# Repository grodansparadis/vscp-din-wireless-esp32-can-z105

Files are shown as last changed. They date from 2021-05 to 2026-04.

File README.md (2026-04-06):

# vscp-din-wireless-esp32-z105
ESP32 based CAN4VSCP FD controller in a single module DIN package with BT and wifi interface.

**Note!** This is still a prototype. ....

The bottom board is here: https://github.com/grodansparadis/vscp-din-m1-base-board-z105

## PCB's
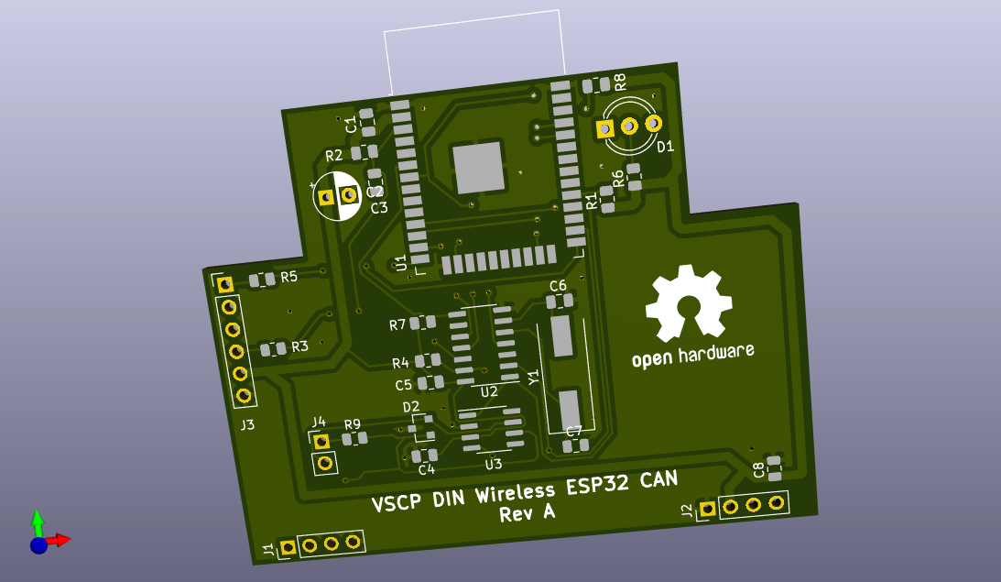
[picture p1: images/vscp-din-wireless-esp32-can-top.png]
Control Interface Top


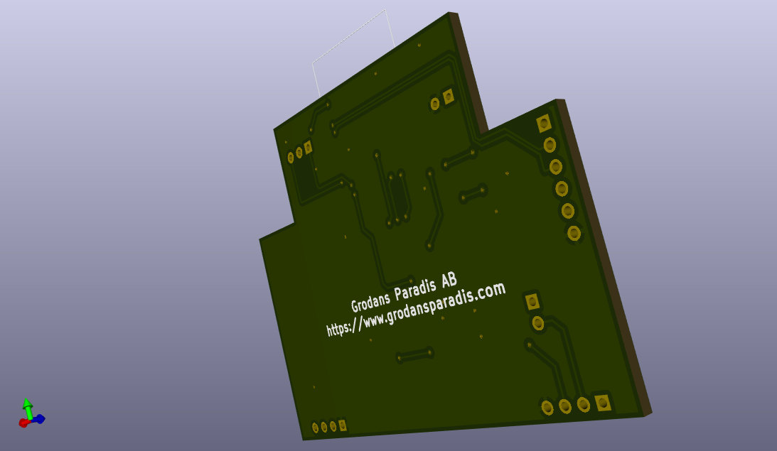
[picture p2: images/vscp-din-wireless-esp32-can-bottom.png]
Control Interface Bottom
 

---

Part of the [VSCP Project](https://www.vscp.org).

Copyright 2021-2026 © Åke Hedman, (Grodans Paradis AB)[https://www.grodansparadis.com]

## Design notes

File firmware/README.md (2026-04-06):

# No firmware here

Firmware is available here: https://github.com/grodansparadis/vscp-din-wireless-esp32-can-z102

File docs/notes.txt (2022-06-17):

CAN Driver
----------
https://github.com/ThomasBarth/ESP32-CAN-Driver

CAN interface using ESP32
-------------------------
https://github.com/nopnop2002/esp-idf-CANBus-Monitor

Open standard for connecting devices to Wi-Fi using Bluetooth LE or Serial
--------------------------------------------------------------------------
https://www.improv-wifi.com/

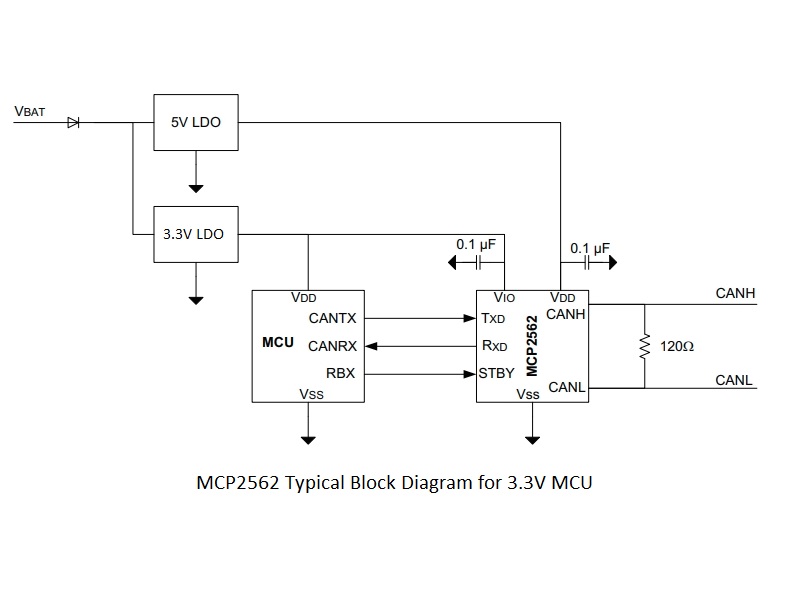
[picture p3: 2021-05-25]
docs/MCP2562-Block-Diagram.jpg

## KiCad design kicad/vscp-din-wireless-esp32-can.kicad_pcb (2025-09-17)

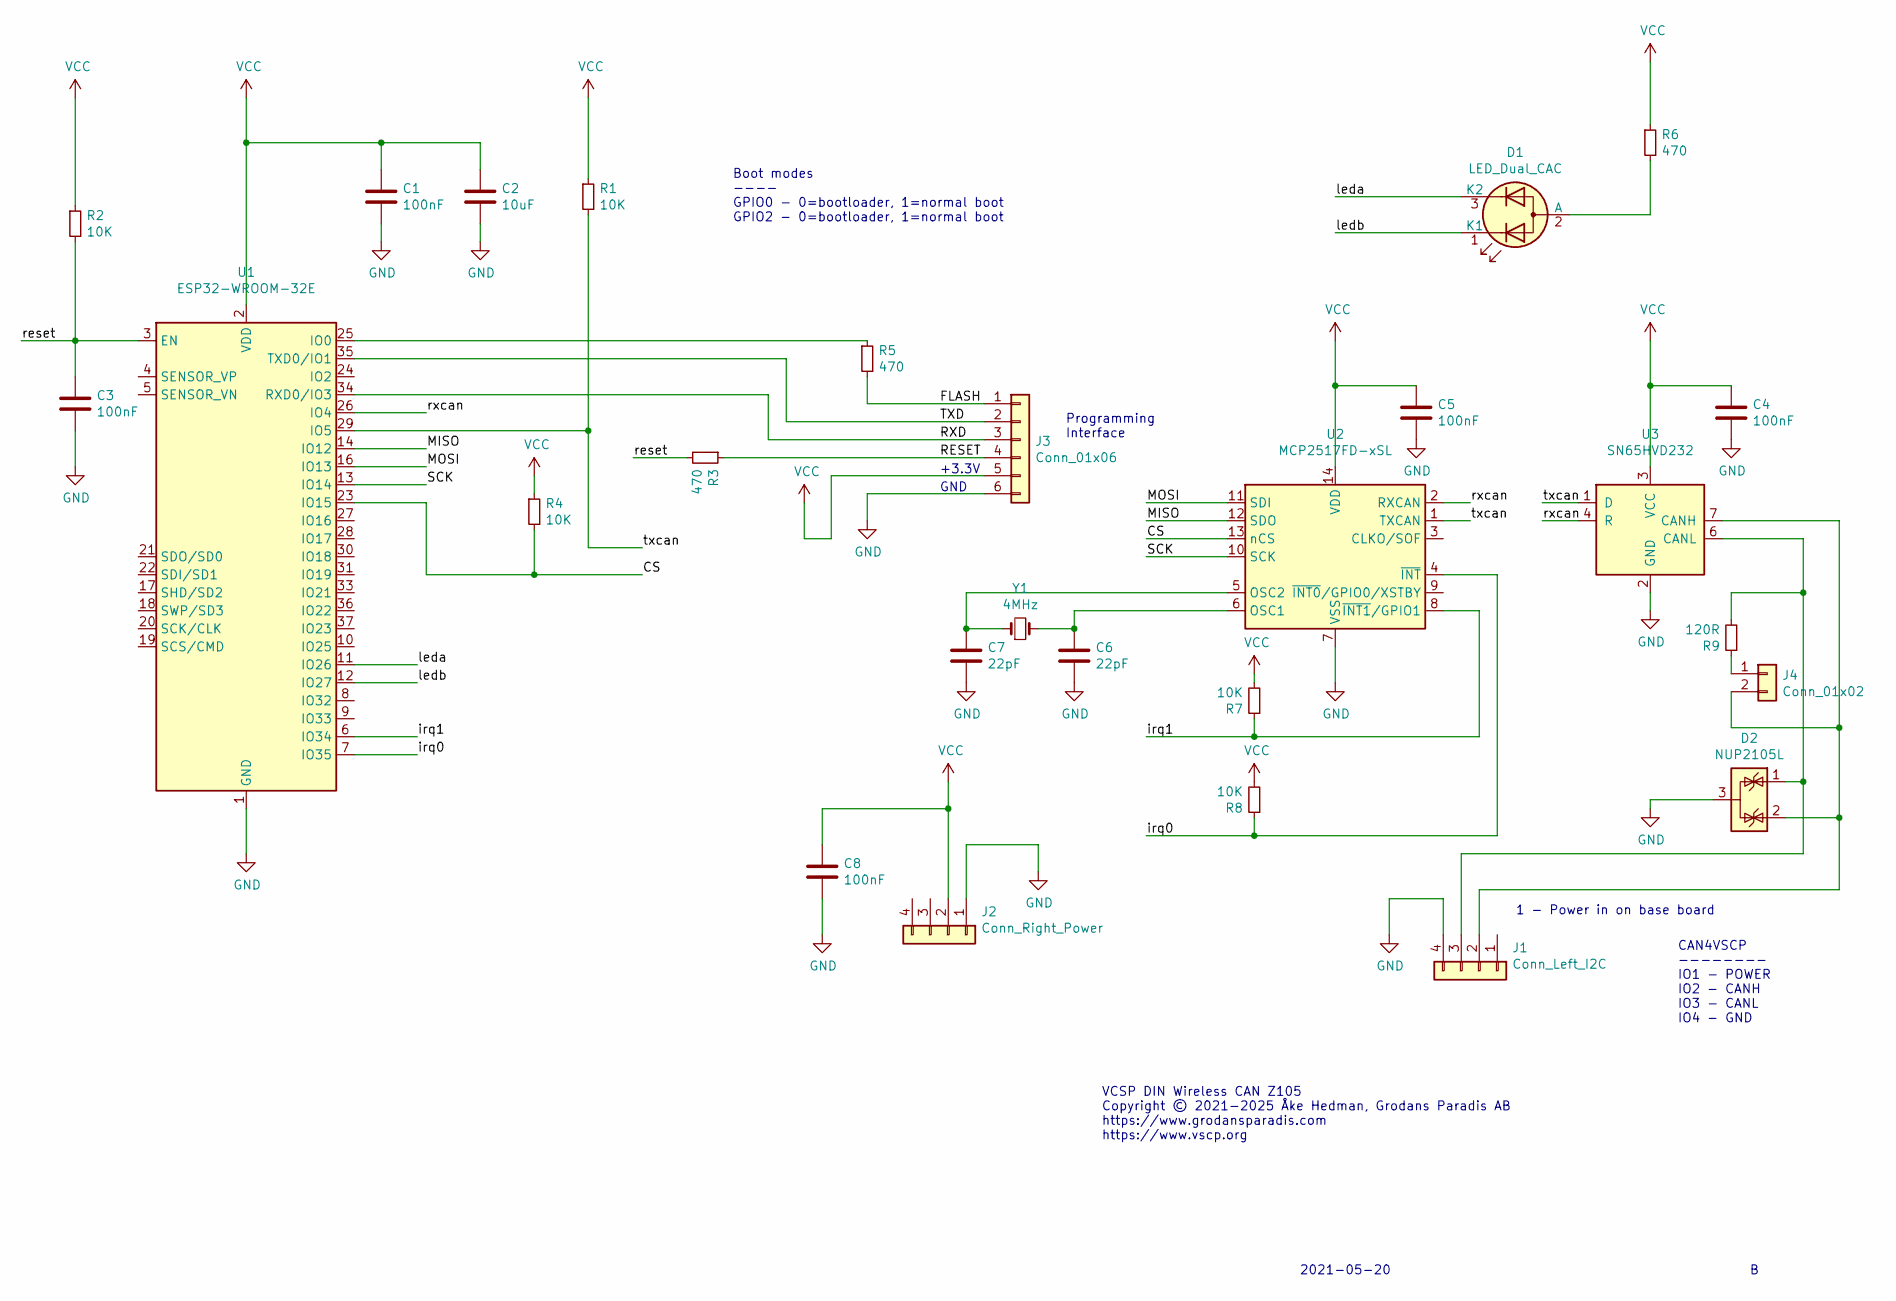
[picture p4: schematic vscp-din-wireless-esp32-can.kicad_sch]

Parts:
C1, C3, C4, C5, C8: 100nF; C_0805_2012Metric
C2: 10uF; CP_Radial_D5.0mm_P2.50mm
C6, C7: 22pF; C_0805_2012Metric
D1: LED_Dual_CAC; LED_D5.0mm-3
D2: NUP2105L; SOT-23
J1: Conn_Left_I2C; PinHeader_1x04_P2.54mm_Vertical
J2: Conn_Right_Power; PinHeader_1x04_P2.54mm_Vertical
J3: Conn_01x06; PinHeader_1x06_P2.54mm_Vertical
J4: Conn_01x02; PinHeader_1x02_P2.54mm_Vertical
R1, R2, R4, R7, R8: 10K; R_0805_2012Metric
R3, R5, R6: 470; R_0805_2012Metric
R9: 120R; R_0805_2012Metric
U1: ESP32-WROOM-32E; ESP32-WROOM-32
U2: MCP2517FD-xSL; SOIC-14_3.9x8.7mm_P1.27mm
U3: SN65HVD232; SOIC-8_3.9x4.9mm_P1.27mm
Y1: 4MHz; Crystal_SMD_HC49-SD

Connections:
/CS: R4.2, U1.23 (IO15), U2.13 (nCS)
/FLASH: J3.1, R5.2
/MISO: U1.14 (IO12), U2.12 (SDO)
/MOSI: U1.16 (IO13), U2.11 (SDI)
/RESET: J3.4, R3.1
/RXD: J3.3, U1.34 (RXD0/IO3)
/SCK: U1.13 (IO14), U2.10 (SCK)
/TXD: J3.2, U1.35 (TXD0/IO1)
/irq0: R8.1, U1.7 (IO35), U2.4 (~INT)
/irq1: R7.1, U1.6 (IO34), U2.8 (~INT1/GPIO1)
/leda: D1.3 (K2), U1.11 (IO26)
/ledb: D1.1 (K1), U1.12 (IO27)
/reset: C3.1, R2.2, R3.2, U1.3 (EN)
/rxcan: U1.26 (IO4), U2.2 (RXCAN), U3.4 (R)
/txcan: R1.2, U1.29 (IO5), U2.1 (TXCAN), U3.1 (D)
GND: C1.2, C2.2, C3.2, C4.2, C5.2, C6.2, C7.2, C8.2, D2.3 (A), J1.4, J2.1, J3.6, U1.1 (GND), U1.15 (GND), U1.38 (GND), U1.39 (GND), U2.7 (VSS), U3.2 (GND)
unnamed: D1.2 (A), R6.2
unnamed: D2.2 (K), J1.2, J4.2, U3.7 (CANH)
unnamed: D2.1 (K), J1.3, R9.2, U3.6 (CANL)
unnamed: J4.1, R9.1
unnamed: R5.1, U1.25 (IO0)
unnamed: C6.1, U2.6 (OSC1), Y1.2
unnamed: C7.1, U2.5 (OSC2), Y1.1
VCC: C1.1, C2.1, C4.1, C5.1, C8.1, J2.2, J3.5, R1.1, R2.1, R4.1, R6.1, R7.2, R8.2, U1.2 (VDD), U2.14 (VDD), U3.3 (VCC)

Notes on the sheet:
+3.3V
2021-05-20
VCSP DIN Wireless CAN Z105 Copyright © 2021-2025 Åke Hedman, Grodans Paradis AB https://www.grodansparadis.com https://www.vscp.org
GND
CAN4VSCP -------- IO1 - POWER IO2 - CANH IO3 - CANL IO4 - GND
Boot modes ---- GPIO0 - 0=bootloader, 1=normal boot GPIO2 - 0=bootloader, 1=normal boot
Programming Interface
1 - Power in on base board

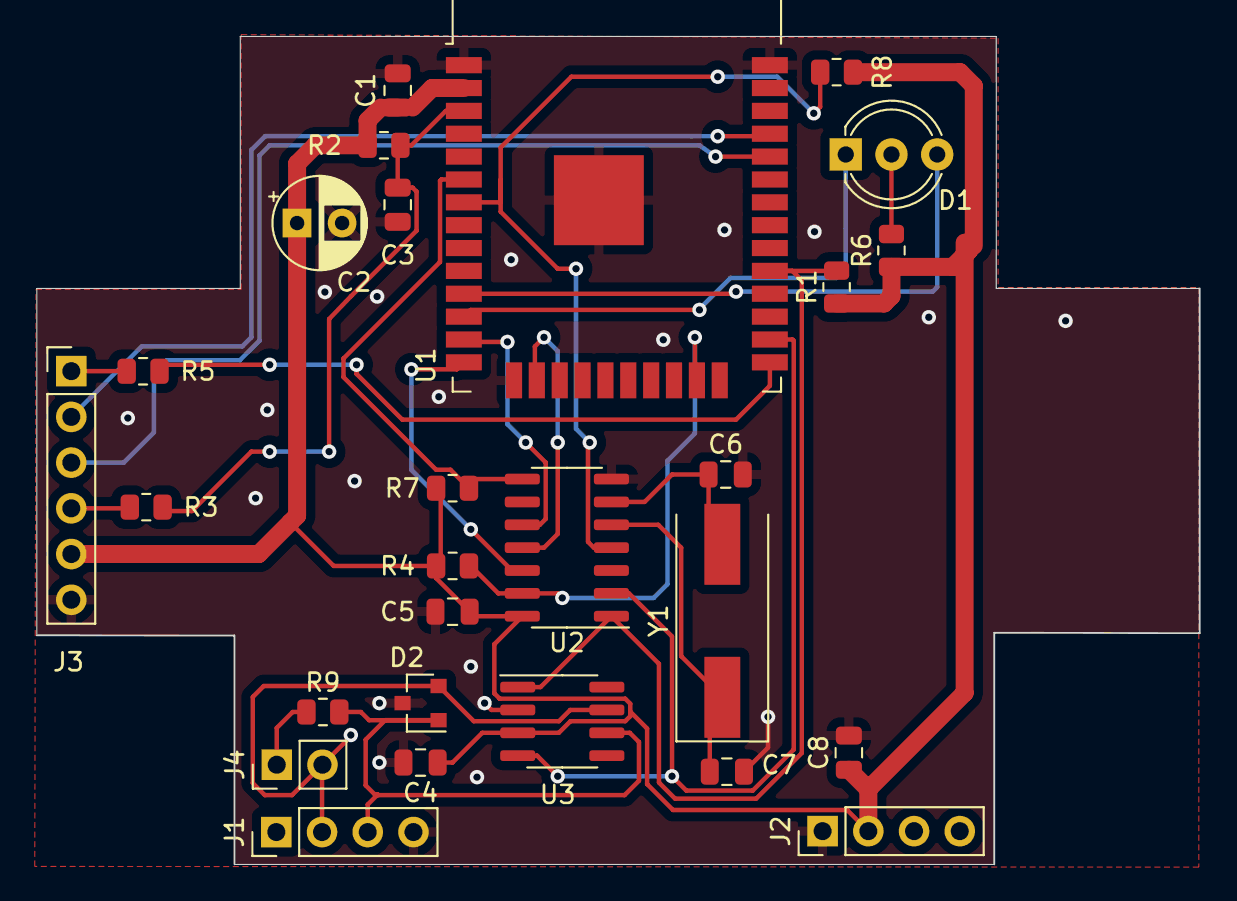
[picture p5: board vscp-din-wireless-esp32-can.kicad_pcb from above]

Board: 2 copper layers, 64.6 x 46.0 mm, 27 parts (0 on the bottom side), 24 nets.

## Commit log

2021-05-24 Init import
    [vscp-din-wireless-esp32-can.kicad_pcb, vscp-din-wireless-esp32-can.sch]
2021-05-25 First version gerbers
    [vscp-din-wireless-esp32-can.kicad_pcb, vscp-din-wireless-esp32-can.sch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]
2021-05-25 Added gerbers
    [vscp-din-wireless-esp32-can-B_Cu.gbr, vscp-din-wireless-esp32-can-B_Mask.gbr, vscp-din-wireless-esp32-can-B_Paste.gbr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]
2021-08-09 shrinked to fit encapsulationy
    Please enter the commit message for your changes. Lines starting
    [vscp-din-wireless-esp32-can.kicad_pcb, vscp-din-wireless-esp32-can.sch]
2022-06-15 Fixed some design errors
    [vscp-din-wireless-esp32-can-B_Cu.gbr, vscp-din-wireless-esp32-can-B_Mask.gbr, vscp-din-wireless-esp32-can-B_Paste.gbr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]
2022-09-02 Added new libs
    [vscp-din-esp32-can-z102-B_Cu.gbr, vscp-din-esp32-can-z102-B_Mask.gbr, vscp-din-esp32-can-z102-B_Paste.gbr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]
2025-09-17 Updated ESP32 module
    [vscp-din-wireless-esp32-can.kicad_pcb, vscp-din-wireless-esp32-can.kicad_sch]
2026-04-06 Updated to KiCad version 10
    [vscp-din-wireless-esp32-can.kicad_sch]
2026-04-06 Moved schema to it's own folder
    [vscp-din-esp32-can-z102-B_Cu.gbr, vscp-din-esp32-can-z102-B_Mask.gbr, vscp-din-esp32-can-z102-B_Paste.gbr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]

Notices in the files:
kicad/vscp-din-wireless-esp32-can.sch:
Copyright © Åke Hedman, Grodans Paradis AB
